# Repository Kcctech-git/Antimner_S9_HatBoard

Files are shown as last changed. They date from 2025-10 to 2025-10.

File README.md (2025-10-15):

# Antminer S9 Control Board HAT
## Disclaimer

Following the global mining boom, large numbers of used Antminer S9 control boards have become widely available on secondary markets for as little as $5–30.
These boards, originally built to control cryptocurrency mining equipment, are based on the well-documented Xilinx Zynq-7010 (XC7Z010) SoC and include:

 - Two Arm® Cortex®-A9 processor cores

 - Gigabit Ethernet

 - 512 MB or 1 GB DDR3 RAM

 - 256 Mb SLC NAND flash

 - MicroSD card

 - Exposed PS–PL interface pins, some of which are connected to various peripherals
 
 - Supports Linux and FreeRTOS

Because of their solid hardware design and abundance, these boards make excellent low-cost development platforms for embedded Linux, RTOS, FPGA, or hardware-software co-design experiments — especially when combined with this HAT expansion board.

## Overview

This project is a KiCad-based expansion board (HAT) designed for the Antminer S9 Control Board built around the Xilinx Zynq-7010 (XC7Z010) SoC.
The board extends the original functionality of the control board by adding:

PS-side ULPI USB controller — enabling standard USB host/device connectivity via the Zynq Processing System.

HDMI output interface — connected directly to the Zynq PL (Programmable Logic) fabric for video output or diagnostics.

Breakout header exposing all remaining available PL I/O pins of the Zynq device (except 8 pins used for HDMI).

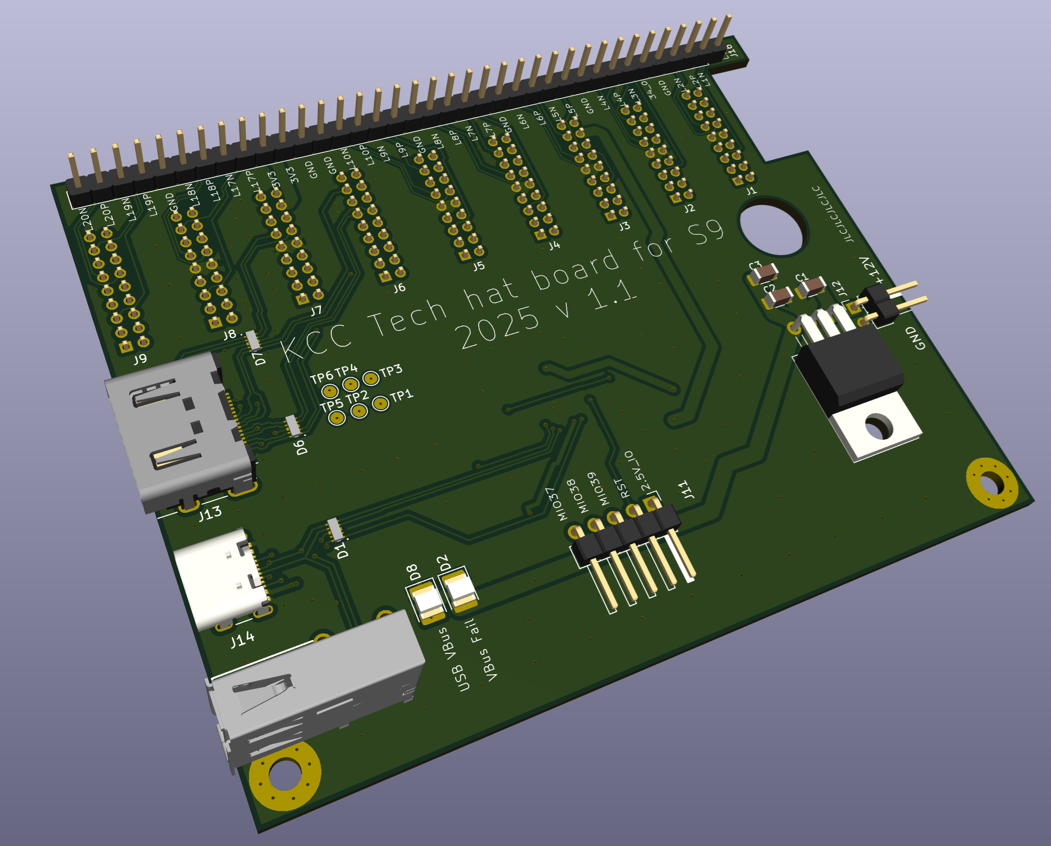
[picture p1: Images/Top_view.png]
3d Top wiew of the board


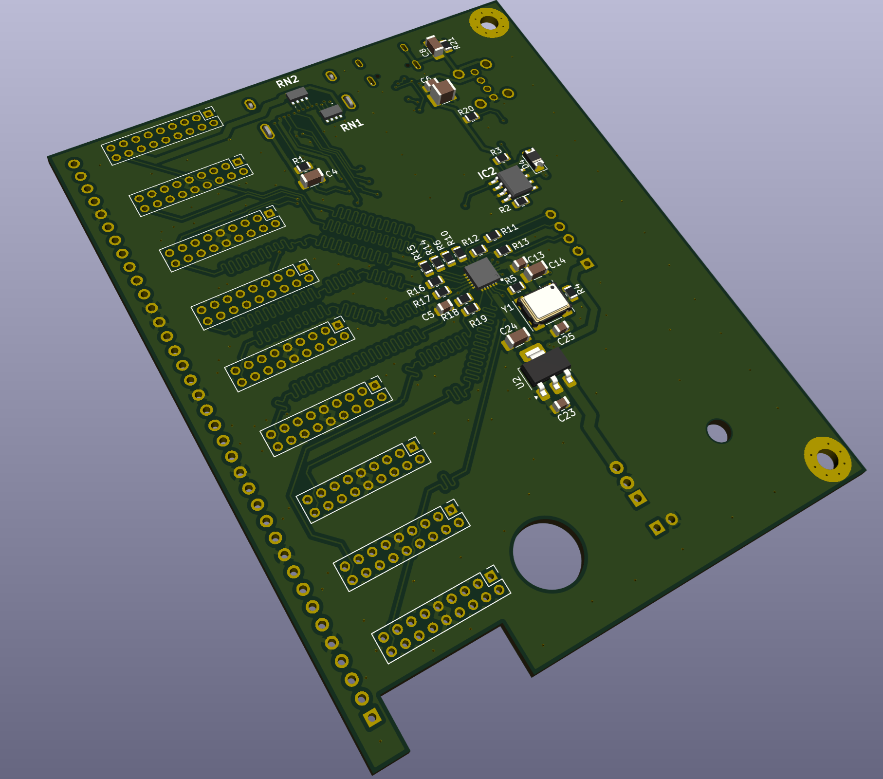
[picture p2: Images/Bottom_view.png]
3d Bottom wiew of the board


The goal of this project is to repurpose the Antminer S9 control board into a versatile FPGA development platform, enabling experimentation with Zynq PS/PL subsystems, video output, and general FPGA prototyping.

## Features

 - Compatible with Antminer S9 Zynq-7010 control boards

 - Adds USB ULPI PHY connected to the Zynq PS

 - Adds HDMI TX output using 8 PL pins for TMDS signaling

 - Breaks out all remaining PL I/O to 2.54 mm header

 - Designed in KiCad 9.0 (schematic + PCB files included)

 - Fits within the mechanical envelope of the S9 control board

### This HAT board enables multiple new use cases for the Antminer S9 Control Board:

 - Use as a Zynq FPGA development board with easy access to PL I/O

 - Implement custom video output via HDMI for FPGA or Linux framebuffer

 - Utilize USB host/device support through the PS-side ULPI PHY

 - Experiment with bare-metal or Linux projects using the onboard DDR, flash, and Ethernet

 - Perform reverse engineering, diagnostics, or educational FPGA projects on low-cost S9 boards

## Purpose of the Design

The main goal of this HAT board was to enable the built-in USB 2.0 controller inside the Zynq-7010 Processing System (PS).
Although the Zynq PS includes a native ULPI interface for USB, its signals on the Antminer S9 control board are routed to scattered locations and are not interconnected in a usable way.

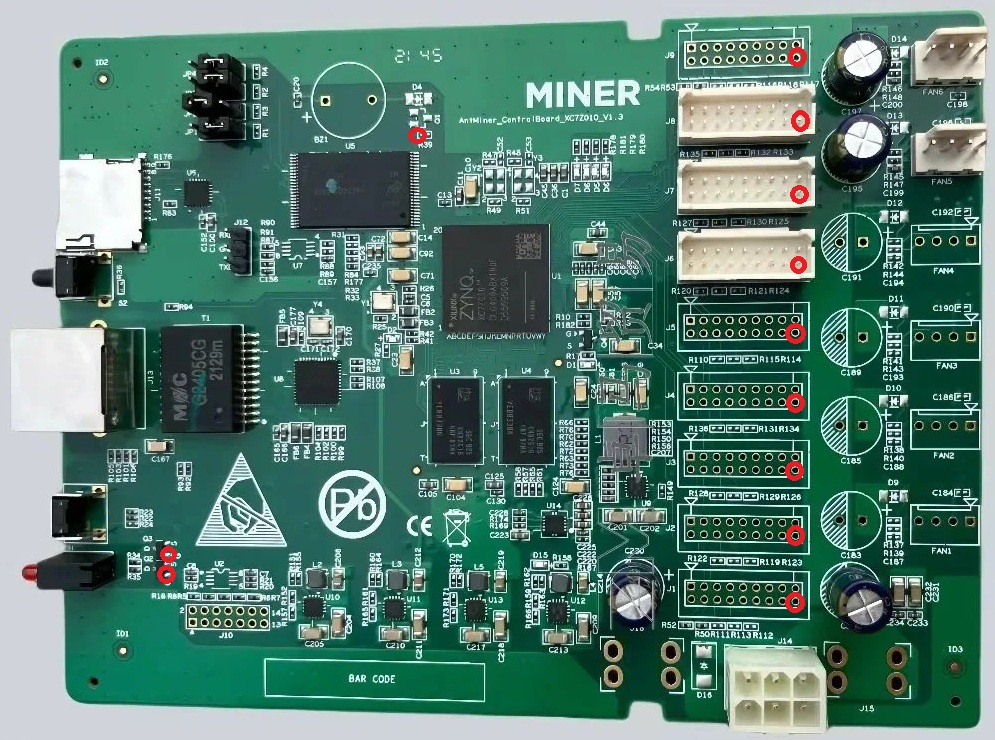
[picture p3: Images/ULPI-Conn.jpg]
ULPI signals on Antminer S9 board


This board collects all required ULPI pins from different areas of the control board, aligns their routing lengths, and connects them to a USB PHY (USB3315C).
Because the parallel ULPI bus operates at approximately 60 MHz, and the trace length on the HAT is around 16 cm — close to the reliable signaling limit — special care was taken to maintain consistent line length and impedance.

To minimize signal reflections, 30 Ω series resistors were added on all ULPI data lines.
Testing confirmed that the USB 2.0 interface operates reliably and stably: files larger than 100 MB can be read and written from a USB flash drive without errors.

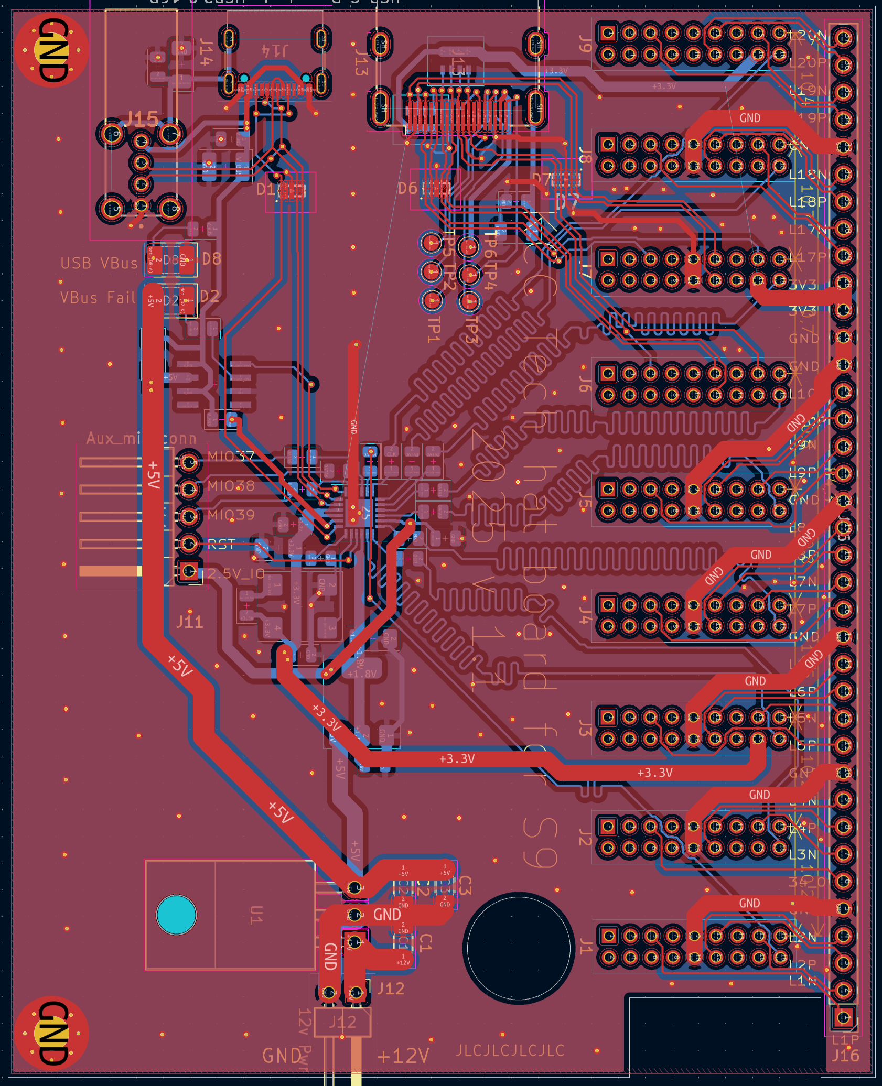
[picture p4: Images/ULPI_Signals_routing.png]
ULPI signals routing


## Hardware Modifications (Required)

To enable the PS-side ULPI USB interface, a few small modifications are required on the Antminer S9 Zynq-7010 Control Board.
These steps free PS MIO pins previously used by on-board peripherals and provide mechanical clearance for the HAT board.

### Steps

1. Remove Q2 and Q3
These transistors are connected to MIO lines needed for ULPI.
Removing them frees access to: PS_MIO37 and PS_MIO38

2. Wire PS_MIO37 and PS_MIO38 to J11
Solder 60 mm insulated wires from the Q2/Q3 gate pads to PS_MIO37, PS_MIO38

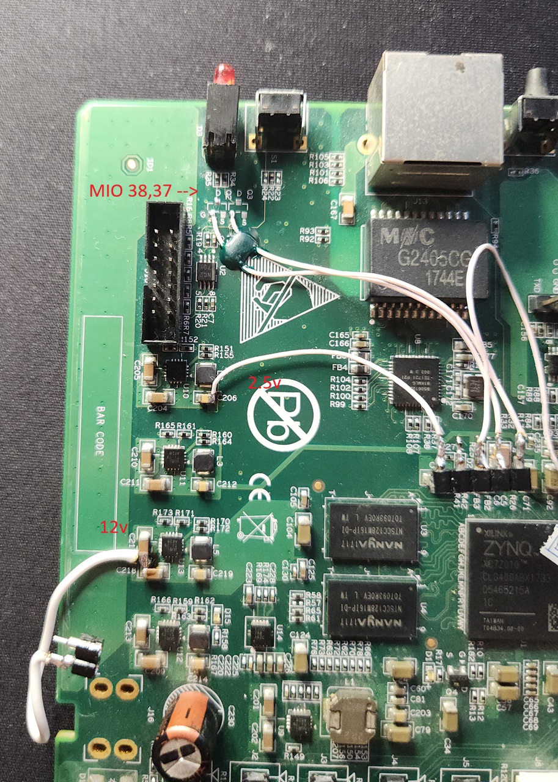
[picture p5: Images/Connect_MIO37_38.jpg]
Connection of PS_MIO37 and PS_MIO38 to J11


4. Wire PS_MIO39 to J11
Solder a 102 mm insulated wire from the resistor pad (previously tied to control logic) to PS_MIO39

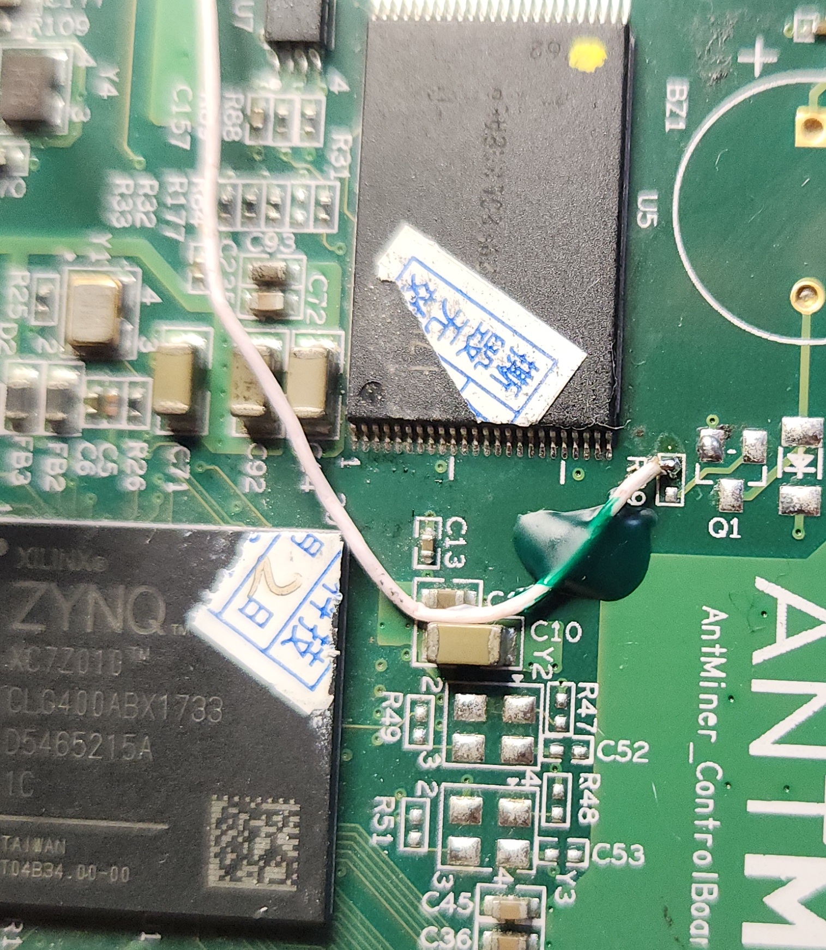
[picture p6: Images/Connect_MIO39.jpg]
Connection of PS_MIO39 to J11


6. Remove capacitors for clearance
Desolder the following mechanically blocking capacitors to allow the HAT board to seat properly C195, C197, C229

7. Connect auxiliary signals to J11 (Aux MIO Connector on HAT)
8. Hook up the freed MIO lines and power signals to the J11 header on the HAT board.
See pinout table below.

9. Provide +12 V to J12 (12 V Pwr on HAT)
10. Connect the +12 V rail from the control board to the J12 input on the HAT.
The HAT generates 5 V and 1.8 V locally for its subsystems.

### J11 (Aux MIO Connector) Pinout
|  Pin	 |  Signal |	Direction	Notes |
| ----- | ---  | --- |
| 1	 | USB_VDD_IO| (2.5 V)	Power	I/O voltage reference for Zynq PS Bank 1 |
| 2	 | RESET |	Input	Optional; not used in the reference build |
| 3 |	PS_MIO39  |	I/O	ULPI signal |
| 4	 | PS_MIO38  |	I/O	ULPI signal |
| 5 |	PS_MIO37  |	I/O	ULPI signal |

### Note: Verify pin orientation according to the silkscreen and schematic before soldering.
Keep wires short (≤ 100 mm) and add strain relief where possible.

### Result:
After completing these modifications, the HAT board’s USB3315C ULPI controller is correctly connected to the Zynq PS USB interface through PS_MIO37–39, with the proper 2.5 V I/O reference and power supplied via J12.

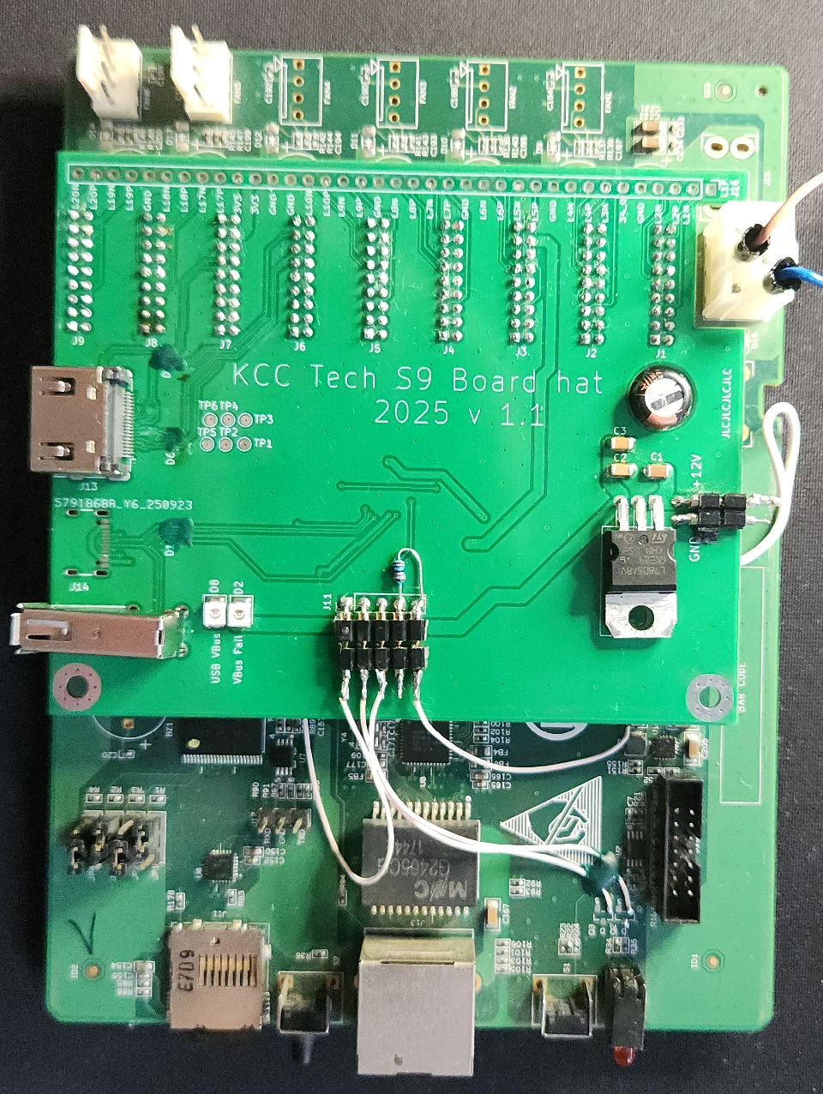
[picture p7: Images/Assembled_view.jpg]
Assembled view of hat board


## Bill of Materials (BOM)

| Ref | Qty | Value | Description / Notes | Footprint / Link |
| --- | --- | --- | --- | --- |
| **USB & Power** | | | | |
| IC1 | 1 | USB3315C-CP-TR | ULPI USB PHY | [Microchip Datasheet](http://ww1.microchip.com/downloads/en/DeviceDoc/3315.pdf) |
| IC2 | 1 | LM3525M-H | USB Power Switch | [TI Datasheet](https://www.ti.com/product/LM3525) |
| J14 | 1 | USB-C Receptacle | USB2.0 16-pin | [USB Type-C Spec](https://www.usb.org/sites/default/files/documents/usb_type-c.zip) |
| J15 | 1 | 48204-0001 | IO Connector (Molex type) | [Molex 48204-0001](http://www.molex.com/webdocs/datasheets/pdf/en-us/0482040001_IO_CONNECTORS.pdf) |
| Y1 | 1 | 24 MHz | ULPI Clock Oscillator | [Abracon ASV](http://www.abracon.com/Oscillators/ASV.pdf) |
| **HDMI Interface** | | | | |
| J13 | 1 | HDMI Type-A | Output Connector | [Molex 208658-1001](https://www.molex.com/en-us/products/part-detail/2086581001) |
| D1, D6, D7 | 3 | CDDFN10-0524P | HDMI ESD Protection | [Bourns CDDFN10-0524P](https://www.bourns.com/docs/Product-Datasheets/CDDFN10-0524P.pdf) |
| **Voltage Regulation** | | | | |
| U1 | 1 | L7805 | 5 V Linear Regulator | [ST L7805](https://www.st.com/resource/en/datasheet/l78.pdf) |
| U2 | 1 | LM1117DT-1.8 | 1.8 V Regulator | [TI LM1117](http://www.ti.com/lit/ds/symlink/lm1117.pdf) |
| **Connectors** | | | | |
| J1–J9 | 9 | Conn_02x09 | PL / GPIO Headers (2 mm pitch) | — |
| J11 | 1 | Aux_mio_conn | 1×5 Header 2.54 mm | — |
| J12 | 1 | 12 V Pwr | 2×2 Socket 2.54 mm | — |
| J16 | 1 | PL_conn | 1×37 Header 2.54 mm | — |
| **Passive Components** | | | | |
| C1 | 1 | 47 µF 25 V | Bulk decoupling | 1206 |
| C2 | 1 | 100 µF 10 V | Bulk decoupling | 1206 |
| C3 | 1 | 100 nF | Decoupling | 1206 |
| C4 | 1 | 1 nF | Filter | 1206 |
| C5, C6, C13, C23, C25  | 5 | 0.1 µF | Bypass capacitors | 0805 |
| C7 | 1 | 100 µF | Bulk capacitor | 1210 |
| C8 | 1 | 1 nF | Filter | 1206 |
| C14, C24 | 2 | 10 µF | Local decoupling | 1206 |
| R1 | 1 | 1 MΩ | Pull-down | 0805 |
| R2 | 1 | 820 Ω | LED limiter | 0805 |
| R3, R20 | 2 | 2 kΩ | General pull-up | 0805 |
| R4 | 1 | 4.7 kΩ | I²C pull-up | 0805 |
| R5 | 1 | 8.06 kΩ | Divider | 0805 |
| R6–R19 | 11  | 30 Ω | HDMI series termination | 0805 |
| R21 | 1 | 1 MΩ | General pull-down | 0805 |
| RN1, RN2 | 2 | TC164-FR-0749R9L | 49.9 Ω resistor network (4×) | [Yageo Datasheet](https://www.yageo.com/upload/media/product/productsearch/datasheet/rchip/PYu-YC_TC_group_51_RoHS_L_9.pdf) |
| D2, D8 | 2 | LED | Status indicators | Any 1206/1210 Leds |
| D4 | 1 | 1N5822 | Schottky diode | [Vishay 1N5822](http://www.vishay.com/docs/88526/1n5820.pdf) |
| **Test Points** | | | | |
| TP1–TP6 | 6 | — | CEC, SCL, SDA, HPD, UTILITY, 5V_HDMI | TestPoint Ø1.5 mm |

## Known Limitations

HDMI interface uses AC-coupled LVCMOS-TMDS signaling (non-standard but functional).

Voltage compatibility of some PL banks depends on existing S9 circuitry — verify I/O standards before connecting.

Power is drawn directly from the S9 board (3.3 V and 12 V rails).

## License

Licensed under CERN Open Hardware Licence v2 - Permissive (CERN-OHL-P)
SPDX-License-Identifier: CERN-OHL-P-2.0

Full license text:
https://ohwr.org/cern_ohl_p_v2.txt

## Credits

Designed by Kanstantsin Salamiyuk

Created to extend and repurpose the Antminer S9 Zynq-7010 control board as an open FPGA development platform.
KiCad design files and documentation are provided for educational and experimental use.

## Disclaimer

This project is not affiliated with or endorsed by Bitmain Technologies.
All hardware modifications and usage are performed at your own risk.
Improper connections may damage the control board or FPGA.

**Tags:** `FPGA` `Zynq-7010` `Antminer S9` `Embedded Linux` `ULPI` `HDMI` `Open Hardware`

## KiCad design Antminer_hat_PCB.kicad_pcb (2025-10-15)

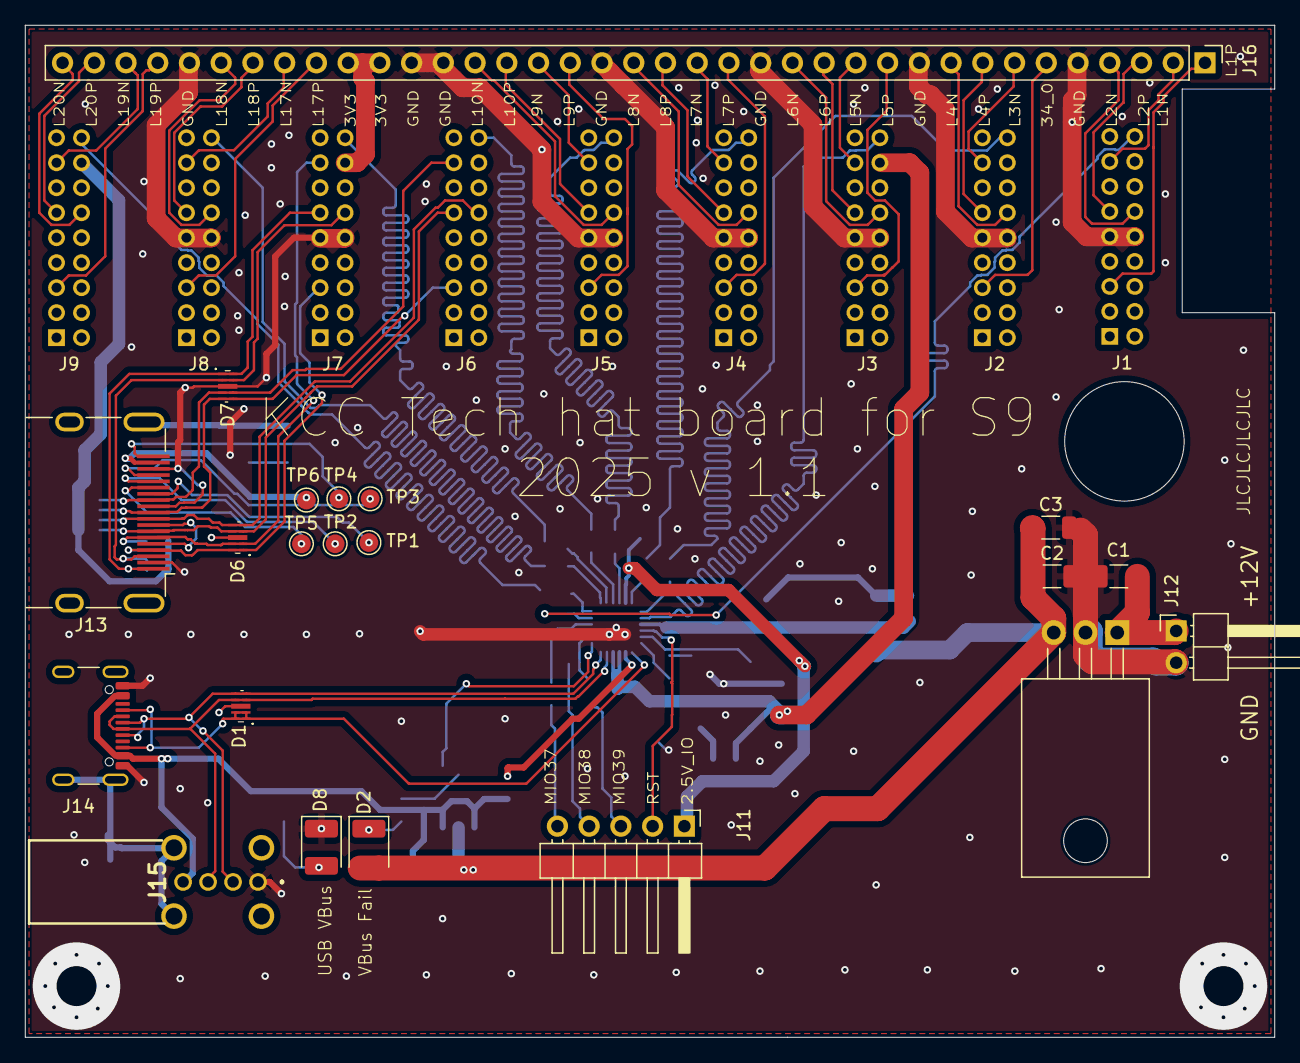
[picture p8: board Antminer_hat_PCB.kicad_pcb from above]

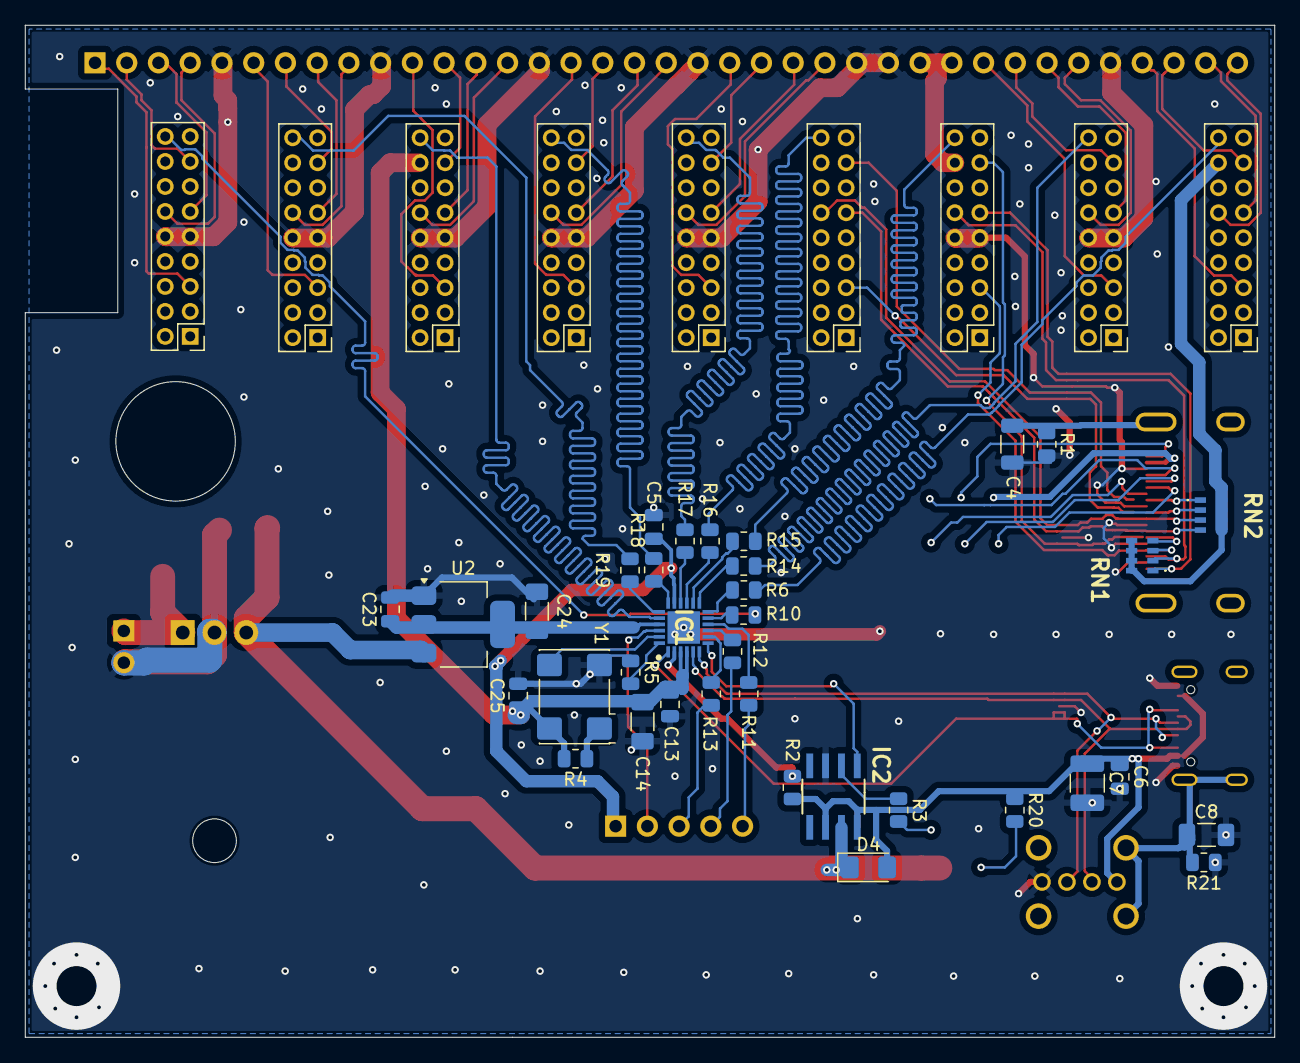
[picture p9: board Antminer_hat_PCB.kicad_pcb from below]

Board: 2 copper layers, 100.0 x 81.0 mm, 65 parts (44 on the bottom side), 86 nets.

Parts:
C1: 47uf 25v; C_1206_3216Metric
C2: 100 uf 10v; C_1206_3216Metric
C3: 100n; C_1206_3216Metric
C4: 1n; C_1206_3216Metric
C5, C6, C13, C23, C25: 0.1uf; C_0805_2012Metric
C7: 100uf; C_1210_3225Metric_Pad1.33x2.70mm_HandSolder
C8: 1n; C_1206_3216Metric_Pad1.33x1.80mm_HandSolder
C14, C24: 10uf; C_1206_3216Metric_Pad1.33x1.80mm_HandSolder
D1, D6, D7: CDDFN10-0524P; CDDFN100524P
D2, D8: LED; LED_1210_3225Metric_Pad1.42x2.65mm_HandSolder
D4: 1N5822; D_1206_3216Metric_Pad1.42x1.75mm_HandSolder
IC1: USB3315C-CP-TR; QFN50P400X400X100-25N-D
IC2: LM3525M-H; SOIC127P620X175-8N
J1, J2, J3, J4, J5, J6, J7, J8, J9: Conn_02x09_Odd_Even; PinHeader_2x09_P2.00mm_Vertical
J11: Aux_mio_conn; PinHeader_1x05_P2.54mm_Horizontal
J12: 12v Pwr; PinHeader_1x02_P2.54mm_Horizontal
J13: HDMI_A; HDMI_A_Molex_208658-1001_Horizontal
J14: USB_C_Receptacle_USB2.0_16P; USB_C_Receptacle_GCT_USB4105-xx-A_16P_TopMnt_Horizontal
J15: 48204-0001 China; 482040001
J16: PL_conn; PinHeader_1x37_P2.54mm_Vertical
R1: 1m; R_0805_2012Metric
R2: 820; R_0805_2012Metric
R3, R20: 2k; R_0805_2012Metric
R4: 4k7; R_0805_2012Metric
R5: 8k06; R_0805_2012Metric
R6, R10, R11, R12, R13, R14, R15, R16, R17, R18, R19: 30; R_0805_2012Metric
R21: 1M; R_0805_2012Metric
RN1, RN2: TC164-FR-0749R9L; TC164FR0749R9L
TP1: CEC; TestPoint_Pad_D1.5mm
TP2: SCL; TestPoint_Pad_D1.5mm
TP3: SDA; TestPoint_Pad_D1.5mm
TP4: HPD; TestPoint_Pad_D1.5mm
TP5: UTILITY; TestPoint_Pad_D1.5mm
TP6: 5V_HDMI; TestPoint_Pad_D1.5mm
U1: L7805; TO-220-3_Horizontal_TabDown
U2: LM1117DT-1.8; SOT-223-3_TabPin2
Y1: 24Mhz; Oscillator_SMD_Abracon_ASV-4Pin_7.0x5.1mm

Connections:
2.5VCC_IO: C5.1, IC1.17 (VDDIO), J11.1
+1.8V: C23.1, C24.1, IC1.21 (VDD1.8), U2.2 (VO)
+3.3V: C13.1, C14.1, C25.1, IC1.3 (VBAT), IC1.4 (VDD3.3), J3.16, J7.16, J9.16, J16.27, J16.28, R4.2, RN1.5, RN1.6, RN1.7, RN1.8, RN2.5, RN2.6, RN2.7, RN2.8, Y1.4 (Vdd)
+5V: C2.1, C3.1, D2.2 (A), D4.1 (K), IC2.7 (IN), U1.3 (OUT), U2.3 (VI)
+12V: C1.1, J12.1, U1.1 (IN)
/BANK34_0_PLUG2: J2.5, J16.6
/BANK34_L1N_RST1: J1.15, J16.2
/BANK34_L1P_PLUG1: J1.5, J16.1
/BANK34_L2N_RXD1: J1.12, J16.4
/BANK34_L2P_TXD1: J1.11, J16.3
/BANK34_L3N_RST2: J2.15, J16.7
/BANK34_L4N_RXD2: J2.12, J16.9
/BANK34_L4P_TXD2: J2.11, J16.8
/BANK34_L5N_RST3: J3.15, J16.12
/BANK34_L5P_PLUG3: J3.5, J16.11
/BANK34_L6N_RXD3: J3.12, J16.14
/BANK34_L6P_TXD3: J3.11, J16.13
/BANK34_L7N_RST4: J4.15, J16.17
/BANK34_L7P_PLUG4: J4.5, J16.16
/BANK34_L8N_RXD4: J4.12, J16.19
/BANK34_L8P_TXD4: J4.11, J16.18
/BANK34_L9N_RST5: J5.15, J16.22
/BANK34_L9P_PLUG5: J5.5, J16.21
/BANK34_L10N_RXD5: J5.12, J16.24
/BANK34_L10P_TXD5: J5.11, J16.23
/BANK34_L11N_RST6: D7.4 (LINE-3), D7.7 (NC_2), J6.15, J13.12 (CK-), RN2.1
/BANK34_L11P_PLUG6: D7.5 (LINE-4), D7.6 (NC_1), J6.5, J13.10 (CK+), RN2.2
/BANK34_L12N_RXD6: D6.5 (LINE-4), D6.6 (NC_1), J6.12, J13.9 (D0-), RN2.3
/BANK34_L12P_TXD6: D6.4 (LINE-3), D6.7 (NC_2), J6.11, J13.7 (D0+), RN2.4
/BANK34_L15N_RST7: D6.2 (LINE-2), D6.9 (NC_3), J7.15, J13.6 (D1-), RN1.4
/BANK34_L15P__PLUG7: D6.1 (LINE_-1), D6.10 (NC_4), J7.5, J13.4 (D1+), RN1.3
/BANK34_L16N_RXD7: D7.2 (LINE-2), D7.9 (NC_3), J7.12, J13.3 (D2-), RN1.2
/BANK34_L16P_TXD7: D7.1 (LINE_-1), D7.10 (NC_4), J7.11, J13.1 (D2+), RN1.1
/BANK34_L17N_RST8: J8.15, J16.30
/BANK34_L17P_PLUG8: J8.5, J16.29
/BANK34_L18N_RXD8: J8.12, J16.32
/BANK34_L18P_TXD8: J8.11, J16.31
/BANK34_L19N_RST9: J9.15, J16.35
/BANK34_L19P_PLUG9: J9.5, J16.34
/BANK34_L20N_RXD9: J9.12, J16.37
/BANK34_L20P_TXD9: J9.11, J16.36
/Usb connection/USB_D+: D1.5 (LINE-4), D1.6 (NC_1), IC1.6 (DP), J14.A6 (D+), J14.B6 (D+), J15.2 (D+)
/Usb connection/USB_D-: D1.4 (LINE-3), D1.7 (NC_2), IC1.5 (DM), J14.A7 (D-), J14.B7 (D-), J15.3 (D-)
/Usb connection/V_BUS: C6.1, C7.1, D4.2 (A), IC2.6 (OUT_2), IC2.8 (OUT), J14.A4 (VBUS), J14.A9 (VBUS), J14.B4 (VBUS), J14.B9 (VBUS), J15.4 (V_BUS), R2.1, R20.1
CLK: J9.18, R6.2
DATA0: J5.18, R17.2
DATA1: J6.18, R16.2
DATA2: J7.18, R15.2
DATA3: J8.18, R14.2
DATA4: J1.18, R10.2
DATA5: J11.5, R11.2
DATA6: J11.4, R12.2
DATA7: J11.3, R13.2
DIR: J2.18, R19.2
GND: C1.2, C2.2, C3.2, C4.2, C5.2, C6.2, C7.2, C8.2, C13.2, C14.2, C23.2, C24.2, C25.2, D1.3 (GND), D6.3 (GND), D7.3 (GND), D8.1 (K), IC1.25 (GND), IC2.3 (GND), J1.9, J1.10, J2.9, J2.10, J3.9, J3.10, J4.9, J4.10, J5.9, J5.10, J7.9, J7.10, J8.9, J8.10, J12.2, J13.2 (D2S), J13.5 (D1S), J13.8 (D0S), J13.11 (CKS), J13.17 (GND), J14.A1 (GND), J14.A12 (GND), J14.B1 (GND), J14.B12 (GND), J15.1 (GND), J16.5, J16.10, J16.15, J16.20, J16.25, J16.26, J16.33, R1.2, R5.1, R21.1, U1.2 (GND), U2.1 (GND), Y1.2 (GND)
NXT: J4.18, R18.2
unnamed: C4.1, J13.SH, R1.1
unnamed: D1.1 (LINE_-1), D1.2 (LINE-2), D1.9 (NC_3), D1.10 (NC_4), IC1.1 (ID), J14.A5 (CC1), J14.B5 (CC2)
unnamed: D2.1 (K), R3.2
unnamed: D8.2 (A), R20.2
unnamed: IC1.12 (CLKOUT), R6.1
unnamed: IC1.7 (CPEN), IC2.1 (EN)
unnamed: IC1.16 (DATA0), R17.1
unnamed: IC1.15 (DATA1), R16.1
unnamed: IC1.14 (DATA2), R15.1
unnamed: IC1.13 (DATA3), R14.1
unnamed: IC1.11 (DATA4), R10.1
unnamed: IC1.10 (DATA5), R11.1
unnamed: IC1.9 (DATA6), R12.1
unnamed: IC1.8 (DATA7), R13.1
unnamed: IC1.19 (DIR), R19.1
unnamed: IC1.18 (NXT), R18.1
unnamed: IC1.24 (RBIAS), R5.2
unnamed: IC1.23 (REFCLK), Y1.3 (OUT)
unnamed: IC1.2 (VBUS), R2.2
unnamed: IC2.2 (FLAG), R3.1
unnamed: J13.18 (+5V), TP6.1
unnamed: J13.13 (CEC), TP1.1
unnamed: J13.19 (HPD), TP4.1
unnamed: J13.15 (SCL), TP2.1
unnamed: J13.16 (SDA), TP3.1
unnamed: J13.14 (UTILITY), TP5.1
unnamed: C8.1, J14.S1 (SHIELD), J15.5 (Shield), J15.6 (Shield), J15.7 (Shield), J15.8 (Shield), R21.2
unnamed: R4.1, Y1.1 (EN)
RST: IC1.22 (RESETB), J11.2
STP: IC1.20 (STP), J3.18

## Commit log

2025-06-23 - Initial commit of PCB
    [cap_pcb.kicad_pcb, cap_pcb.kicad_sch, hdmi.kicad_sch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]
2025-06-24 - Added capacitors on HDMI TDMS lines
    [cap_pcb.kicad_pcb, cap_pcb.kicad_sch, hdmi.kicad_sch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]
2025-10-14 Updates for version 1.1: - Project named as Antminer_hat_pcb - Added USB3315 Phy on board - Removed ULPI connector - Optimized HDMI wiring - Other updates
    [Antminer_hat_PCB-CuBottom.gbr, Antminer_hat_PCB-CuTop.gbr, Antminer_hat_PCB-EdgeCuts.gbr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]
2025-10-15 - Added board pictures
2025-10-15 - Updated schematic to use correct type of external connectors
    [Antminer_hat_PCB.kicad_pcb, Antminer_hat_PCB.kicad_sch, hdmi.kicad_sch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]
2025-10-15 Update README.md
    - Added pictures to readme
    - Updated pinout for J11 according to schematics modifications
2025-10-15 Clarify purpose and features in README
    - Updated the README to clarify the purpose and features of the Antminer S9 Control Board HAT. Added details about hardware modifications and improved formatting for better readability.
